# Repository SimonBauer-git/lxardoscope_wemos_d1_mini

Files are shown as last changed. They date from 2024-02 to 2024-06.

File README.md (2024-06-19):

# lxardoscope_wemos_d1_mini
this is a single channel low frequency oscilloscope using a wemos d1 minis internal adc. you can use it just with the board itself but i have made a little daughterboard which that makes it more like a real oscilloscope.
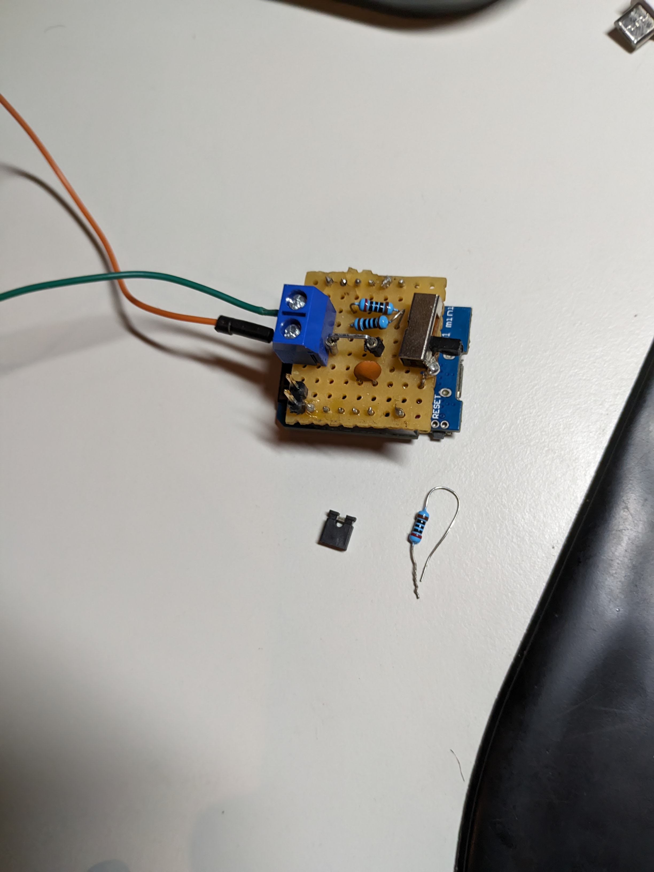
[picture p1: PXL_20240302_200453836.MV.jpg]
Alt the little daughterboard on the wemos board (able to meassure ac)

this is version 2 of the daughterboard, it can meassure ac voltages with the use of a voltage devider. you need a 200k resistor depending on the voltage meassured.
## continous aquisition
with continous aquisition (i.e. reading one sample, then transmitting that), 45ksps is possible or 22.5khz (so anything in the audio frequency range). 62ksps is possible or 31khz if you change the cpu frequency to 160mhz (can be done in arduino IDE). this methode is particularly suited for low frequency stuff.
## buffered aquisition 
by reading a lot of samples (in this case 24k) and then transmitting them in bulk much greater sampling rates are achivable, how much I am not sure of myself as due to the pulsed nature of the datastream the lxardoscope application doesnt show it correctly, I tested it with a 1 microsecond pulse though and it showed up as a squarewave, that was ok in terms of stability, so atleast 500khz. I have done some tweaks to make the trace more stable, particularly at frequencies below 1khz, i have asigned fixed values to tspan and nbchar in lxa_ard.c, to match the hardware.
# using it on x86 linux
just download the lxardoscope code for linux, specify 2000000 BAUD in the code and use it, no extra steps required if you use the continous sampling methode, if not use my code.
## using it on windows
either use a linux vm and then do the same as on x86 linux or use wsl. you need wsl-usb to be able to use the usb from the computer on wsl.
## using it on android (no longer in active developement)
this is no longer in active developement due to application stability issues, you can however mod the code like described above and below.
Alt my scope running on an android tablet
### with proot-distro already setup with a desktop enviroment
just download the folder android from here. you need to install libforms-dev and ibforms-bin to use it and to compile it. you need the app tcp uart transparent bridge, specify it to be server in the app.
https://play.google.com/store/apps/details?id=com.hardcodedjoy.tcpuart
to use it open a terminal in the folder, type ./scopeconnect.sh (assuming you made it executable with chmod +x or in the gui at first) then type ./lxardoscope (if the programm crashes the first time, then repeat this step). and afterwards you can use it.
### simple setup, just the scope
if you only want the scope and nothing more, just install termux, termux x11 and tcp uart bridge. open termux, then do these steps

1. pkg update
2. pkg upgrade
3. pkg install x11-repo termux-x11-nightly
4. pkg install proot-distro
5. proot-distro install debian
6. wget https://raw.githubusercontent.com/SimonBauer-git/lxardoscope_wemos_d1_mini/main/android/simple-setup/scope.sh
7. proot-distro login debian
8. apt update
9. apt upgrade
10. apt install libforms-dev libforms-bin libx11-bin libx11-dev
11. wget https://raw.githubusercontent.com/SimonBauer-git/lxardoscope_wemos_d1_mini/main/android/lxardoscope
11.1 wget https://raw.githubusercontent.com/SimonBauer-git/lxardoscope_wemos_d1_mini/main/android/lxardoscope_0.95_android_sampling.vfast/lxardoscope
12. chmod +x lxardoscope
13. wget https://raw.githubusercontent.com/SimonBauer-git/lxardoscope_wemos_d1_mini/main/android/simple-setup/proot-distro/scope.sh
14. chmod +x scope.sh
# Function Generator:
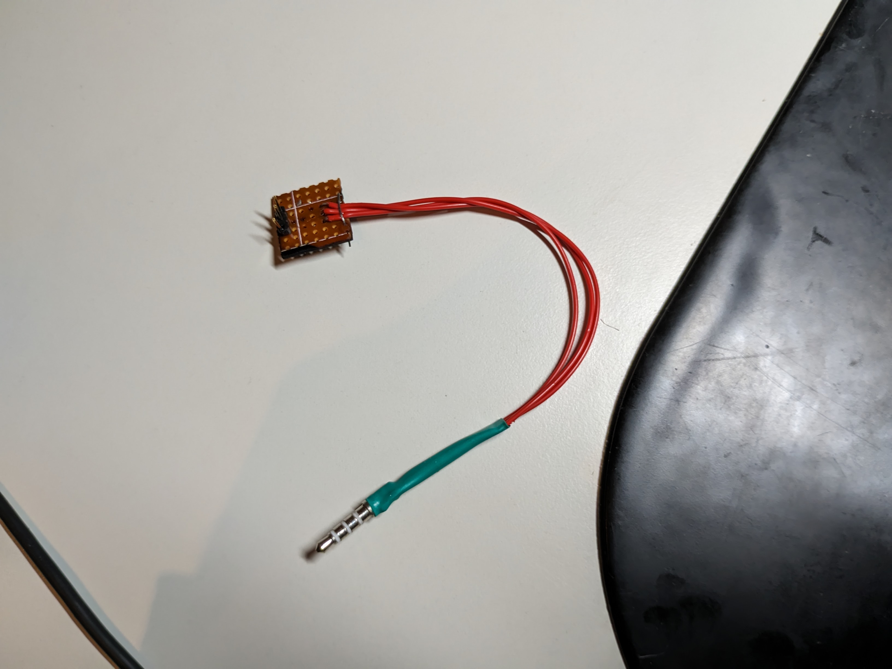
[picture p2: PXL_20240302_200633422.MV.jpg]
function generator

A very simple function generator, using an audio jack output (Frequency limited to whatever the device can provide). daughterboard breaks out left and right channel along with ground to pins, no electronics involved, just a direct connection. you can use something like this to create the waveforms, no install required, just use it: https://cse.unl.edu/~jfalkinburg/husker-scope/app/page/FunctionGenerator
or if you want an android app that has a different interface and a bit more functions look here: https://play.google.com/store/apps/details?id=com.keuwl.functiongenerator

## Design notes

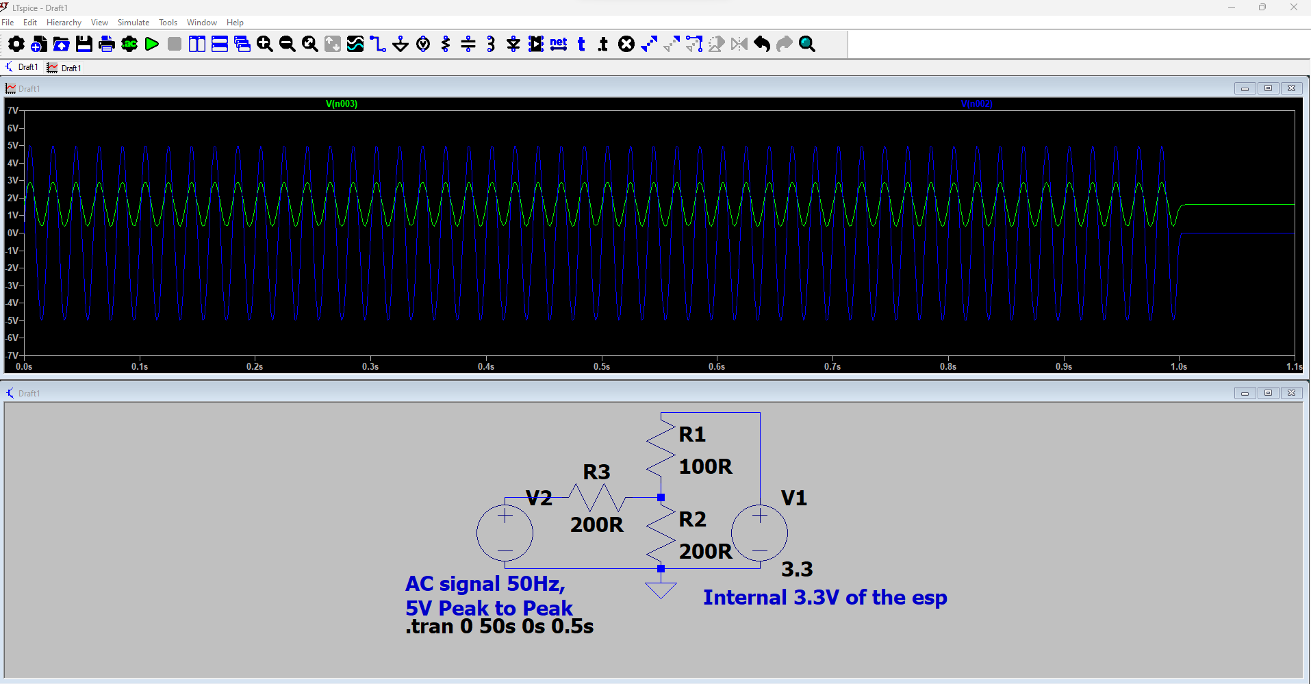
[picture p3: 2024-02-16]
schematic/wemos shield v2/Screenshot 2024-02-16 115349.png

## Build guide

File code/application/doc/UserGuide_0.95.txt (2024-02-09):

/*
 *
 * This file is part of the LXARDOSCOPE package.
 *
 * LXARDOSCOPE is an Arduino based oscilloscope for Linux, using the Xforms library.
 *
 * Copyright (C) 2013 Oskar Leuthold
 * 
 * LXARDOSCOPE is free software: you can redistribute it and/or modify
 * it under the terms of the GNU General Public License as published by
 * the Free Software Foundation, either version 3 of the License, or
 * (at your option) any later version.
 *
 * LXARDOSCOPE is distributed in the hope that it will be useful, but
 * WITHOUT ANY WARRANTY; without even the implied warranty of
 * MERCHANTABILITY or FITNESS FOR A PARTICULAR PURPOSE.  See the GNU
 * Lesser General Public License for more details.
 *
 * You should have received a copy of the GNU Lesser General Public
 * License along with LXARDOSCOPE; see the file COPYING.  If not, write to
 * the Free Software Foundation, 59 Temple Place - Suite 330, Boston,
 * MA 02111-1307, USA.
 *
 */

Introduction
************
LXARDOSCOPE (LinuX-ARDunio-oscillOSCOPE) is a software implementation of an 
oscilloscope in LINUX, using the Analog-Digial converter of an ATmega328 device
or an ArduinoUNO board for data acquisition. 
My goal was to keep the LXARDOSCOPE GUI as intuitive as possible for users who are
familiar with hardware oscilloscopes. I am assuming that the vast majority of 
users fall into this category, since this is a measuring instrument for use with
electric circuits. Therefore this user guide does not cover how to use an 
oscilloscope; tutorials for oscilloscopes are available on the internet. Extra
functions provided here should be self explanatory - otherwise submit a request
for clarification through the Sourceforge support page.
When LXARDOSCOPE is running on my laptop, with CPU clock at 1.8GHz, under
Mint 13, LXARDOSCOPE needs about 2% CPU time with 5 seconds of data displayed.
Xorg's graphics engine needs more, depending on the amount and extent, basically
how many pixels must be processed.  
Lxardoscope_0.95 is designed to work with a preamplifier, which is described
in a separate document, LxaPreamp.txt. This program allows for controlling the 
GND/AC/DC configurations of the preamplifier from the GUI.

Features
********* 
	- display modes: two channels, time/add/xy
	- vertical: 2mV to 10V per division
	- overall gain control for calibration
	- horizontal: 2ms to 5 sec (full sweep)
	- trace position adjustments: vertical and horizontal
	- trigger: on/off, channel and edge selection
	- trigger level: -10 to +10V
	- hysteresis up to 5V
	- signal measurements: max, min, pp, avg, rms
	- display signal levels and timing at cursor position
	- close to 2500 samples per second, per channel
	- option for reviewing snapshot of data
	- option for recording input data stream to file
	- option to display recorded data from file
	- timebase calibration adapting to ADC's conversion speed
	- remote control of GND/AC/DC circuit configurations of the preamplifier.
	- highpass with corner frequency of 2.5Hz in AC mode

Arduino vs ATmega328
*********************
The Arduino UNO board contains the ATmega328 circuit and a chip to communicate
with the USB port of a host computer. Most of the time I use the ATmega328 DIL
circuits on breadboards, with a CP2102 based TTL/USB module for communicating
with the computer's USB port. I prefer the modules from BAITE (available on 
Ebay), which allow for easy replacing the RESET signal with DTR. 
All the detailed testing was done with the ATmega32 on breadboard with the 
BAITE module. The ArduinoUno works fine with this program on Mint9, but not re-
liably on Mint13, for unknown reasons. When connecting a BAITE device to the TX
pin of the Arduino board, I got the expected behavior. So the wiring was correct;
it seems like Mint13 and the TTL/USB converter implemented on the ArduinoUno do
not get along with each other. If you have an idea what is going on, then please
let me know through Sourceforge.

LXARDOSCOPE differences with respect to a conventional oscilloscope:
********************************************************************
The display is not updated continuously, but rather shows a snapshot of the data 
approximately every 300ms. Thus with long time scales, the waveform seems to
move from right to left; therefore a particular event can show up several times.
As opposed to an analog oscilloscope, which operates with signals continuous in
time and levels, LXARDOSCOPE works on the data points from the ATmega, which 
converts the real signal to discrete samples in time and levels. The display
shows simple linear interpolation between these data points, which is admittedly
in general a poor approximation of the true signal. Another source of discrepancy
are signal components input to the ATmega above 1.2kHz (half the sampling rate);
they appear folded into components below 1.2kHz. This folding process is not 
specific to this application, but rather a general property of any sampling
process. And finally the fact that the ATmega samples the two channels in an
alternating fashion creates additional artifacts (see below).     
In LXARDOSCOPE the time base setting is in terms of full scale, not graticule
division. This is based on considerations of the scaling process. For example,
if full scale is set to 12ms, the LXARDOSCOPE graticule shows 13 vertical
lines at 0, 1, 2 ...  10, 11, 12 ms, which is easy to read. On a division based
approach, always 10 divisions are used. For 12ms full scale, the increments are
1.2, thus producing grid lines at 0, 1.2, 2.4 .....10.8, 12, which are much less
convenient to read. 

Development
***********
LXARDOSCOPE version 0.95 has been developed and tested on Linux Mint13 (32bit)
with ATmega328 devices, using the included lxardoscope95.ino (in the ATmega 
directory). 

Installation
************
The downloaded file contains an executable, which hopefully works on your computer.
The appropriate XFORMS executable is linked statically, to simplify installation
and to eliminate problems with incompatible versions of the library, which might
exist on the host computer.
After unpacking the downloaded file, cd to the lxardoscope directory and type
" ./lxardoscope " (without quotes).
For a general installation, type
either " sudo make install "
or " sudo cp lxardoscope /usr/local/sbin "
After installation, the system wide start command is " lxardoscope ".

If the supplied executable does not run on your system, you can re-compile:
1. install libx11-dev (using apt, Synaptic)
2. build:   " make "
4. install and run as above

If these steps do not work, you have to rebuild the Xforms library, which will
produce a new libforms.a. LXARDOSCOPE requires XForms Version 1.0.93sp1. The
directory xforms-1.0.93sp1_ext contains the files which might have to be updated.
The XForms source package is available at 
	http://savannah.nongnu.org/projects/xforms .

Port issues
***********
On Ubuntu style LINUX distros, when connecting the Arduino UNO to the USB port, a
device with a name starting as ttyACM is created in the /dev directory, which can
be accessed like a regular serial port. If you remove the Arduino and reconnect
again, the port number might change, for example from ttyACM0 to ttyACM1.
With the CP2102 based Serial-to-USB converter circuits mentioned above, a device
with a name starting as ttyUSB is created.
If you have a computer with a serial port, then you can connect to an ATmega328
using a simple inverter, as shown in ATmega328simple.png. The schematic 
Interface.png shows a solution with a MAX232, and how optocouplers can be
used to insulate the supplies of the ATmega (and with it the analog signal
processing circuitry) from the PC. When working with the regular serial ports,
keep in mind that the signal levels can be up to 15V. Some integrated circuits
are destroyed if such a high voltage is applied to a pin.

How to get started
******************
First you need to program the ATmega with the supplied sketch lxardoscope95.ino 
from the ATmega/lxardoscope95 directory, using the Arduino IDE or Gnoduino
(used on Mint9, but not on Mint13).
Connect your analog signals to the preamplifier inputs.
Two startup modes are available:
1. choose serial port at startup:
   type " lxardoskope /dev/ttyXXXX " with XXXX being the device name/number. The
   program tries to initialize this port, but others can be selected later.
2. choose serial port on GUI:
   type " lxardoskope " . After starting up, the "Port" pulldown of the GUI is
   populated with the port choices available from the /dev directory. The list
   includes device names which start with "ttyS", "ttyACM" or "ttyUSB".
If the selected port is busy due to some other process, then the initialization
fails. A message is displayed in the terminal where LXARDOSCOPE was started,
if the selected device is not available. 
On success, the START button under the waveform area is enabled. Clicking the
button starts the GND calibration routine. The scope display shows the calibration
results (in units of LSB [least significant bits of the ADC]) for both channels.
The numbers are close to 400 for the preamplifier described in LxaPreamp.txt, 
because the ATMEGA reference voltage is 3V and the actual voltage coming into
the ADC is 1.2V, when the preamplifier input is connected to GND.
After calibration, the ATMEGA device starts acquiring the input signal and 
LXARDOSCOPE displays the data. The pulse indicator changes color from grey, 
and then blinks in response to the serial data stream from the ATMEGA. 
At least some horizontal lines should be displayed, maybe already some waveforms.
Then make the necessary adjustments to the timebase and vertical scale and
position, as on a conventional oscilloscope.
In display mode ADD, position and scale are taken from channel 1; entries for 
channel 2 are disabled. In display mode X-Y, the selected trigger channel is 
displayed in horizontal direction (independent whether triggering is enabled or
not). 
When triggering is enabled, source channel, edge, trigger level and hysteresis
can be selected. The displayed waveform can be shifted to the left or to the 
right, up to 500ms. This is useful for inspecting what happens immediately before
the trigger time point. 
The displayed signals can be measured by placing the cursor with the mouse and
clicking at the time slice of interest. Time and levels are reported in the
" Signal Values " box. The measurement applies to the data displayed at the
moment the selection is made; the value is not continuously updated sub-
sequently.
After clicking the START/STOP button again, acquisition of new data stops and
the internally stored waveforms can be inspected. Vertical Position and Scale,
horizontal Full Scale and (with trigger) DisplayShift functions allow for zooming
into the waveform. With DisplayShift, about half a second of data can be reviewed
and measured using the cursor. 
  
Storing and reviewing data stream
*********************************
The data stream coming from the ATmega can be recorded to a file by clicking the 
"Record" button before the "START" button. A new window pops up for entering
the name of the new file (suggested extension is "raw"). When finished recor-
ding, click the "STOP" button, and toggle the " Record " button to stop recor-
ding and to save the file. The "Record" button is disabled when LXARDOSKOPE is
running. The raw file contains 16-bit (2-byte) sample values, for both channels,
no information on data rate. Of the 16 bits, only 10 are used, because that's 
what the ATmega analog-digital converter delivers. 
To inspect a raw file, select "file" on the "Device" pulldown (last entry). 
A new window pops up for selecting the raw file. The file is loaded, and
the beginning is displayed. The GUI changes in the Timebase area. A counter is
added for navigating in the file under the Full Scale counter, with the following
functionality:
	- single right arrow: shift display to later data, by 20% of full scale.
	- double right arrow: shift display to later data, by 80% of full scale.
	- singe left arrow: shift display to earlier data, by 20% of full scale.
	- double left arrow: shift display to earlier data, by 80% of full scale.
The amount of shift is close to the values indicated; differences are due to
rounding.
Between the navigation buttons, the position of the first sample, shown on the
left side of the waveform display, is indicated, in units of milliseconds.
Commas are used to separate the seconds from the milliseconds, and the seconds
from the thousand seconds. This area is actually an input field, accepting a 
floating point number; the blue vertical line shows the position of the cursor.
In the waveform display area, a yellow line is shown at the end of data, to
distinguish from the case when the data itself is zero.
A 4-digit pushwheel widget allows for setting the Sampling Rate, between 1000
and 5000 samples per second. For accurate time measurements, the value must be
set to the one reported when recording the file (using the Verbose button). 

Communication with the ATmega and Preamplifier
**********************************************
Each channel has 4 separate modes of operation. A corresponding code is sent
to the ATmega device upon selecting a new entry. With the preamplifier described
in the document LxaPreamp.txt, the codes and associated features are shown in the
following table:

		channel1	channel2
mode	code		code
GND		1			4			GND calibration: preamp input connected to GND
DC		2			5			DC: input range is -4V to +6V
AC		2			5			AC: input range is -4V to +6V
AC 10X	3			6			AC with gain: input range is +/-0.5V

When the START button is pressed, a GND calibration is executed for both channels.
In the two AC modes, a highpass filter is implemented in this LXARDOSCOPE program
with a corner frequency of 2.5Hz. 
LXARDOSCOPE adjusts the scaling factor automatically when selecting the AC 10X
mode. If the gain of the preamplifier is different, then you can click the 
"Options" button in the ATmega field and change the gain value in the popup
window. Acceptable values are integers between 1 and 10 (inclusive), with default
at 10.

Sampling rate
*************
When using the supplied lxardoscope95.ino for the ATmeg328, with the transfer
rate of 115200 baud, LXARDOSCOPE starts up assuming 2500 samples per second. The 
actual rate at which data is delivered is continuously measured and the display
settings updated in regular intervals.  
After pressing the push button "Verbose", the actual sampling rate is reported in
the terminal.  
Preliminary tests indicate that the time required for analog-digital conversion
is about the same as the data transfer time; thus by speeding up the data
transfer, the converter becomes the bottleneck (unless accuracy is sacrificed
for speed). Therefore LXARDOSCOPE version 0.95 supports only a fixed transfer
rate of 115200 Baud. 

Alternate Sampling
******************
The ATmeg328 samples channel 1 and channel 2 in an alternating fashion; this means
not at the same time. In "Time" mode, LXARDOSCOPE displays channel 2 delayed
by half a sample with respect to channel 1. Thus when feeding the same signal
into both channels, they line up correctly; although for higher frequency signals
the data points can clearly be seen as alternating.
In "ADD" mode, the signals are interpolated and shifted, such that when feeding
the same signal into both channels, and inverting one of them, the resulting
signal is very small.
In "XY" mode, the signals are not adjusted; therefore when feeding the same
signal into both channels, the delay can clearly be seen: for a sine wave, an
oval shape is shown. 
When feeding identical square waves into both channels, things get really ugly...

ATmega code
***********
The .pde file from previous versions had to be updated to work with Arduino1.0;
lxardoscope95.ino is the new version. The upgrade of the Arduino software required
changes in the communication part: 
	Serial.print(lb|96,BYTE);
replaced by 
	Serial.write(lb|96);
Due to some clever un-optimization from the Arduino folks, this simple change
causes the program to produce a sample rate of 2441 instead of 2940. The addi-
tional code required for programming the relays of the preamplifier and port
switching cause another reduction in sampling rate to 2349. Optimizing this code
by using direct addressing of the peripherals should be a fun and rewarding
exercise. However at that point one might just go for overall higher speed,
including higher transfer rate on the port (subject of the next LXARDOSCOPE 
version?).
In the sketch lxardoscope95.ino, the loop section is digitizing the signals on
ports A0 and A1 in DC mode, and on ports A2 and A3 in AC mode, and sending the
result after some formatting through the serial port to the USB link. In the
middle and at the end of the loop, port 8 is switched to produce a square wave,
which is used to drive the auxiliary power supply of the preamplifier. 
Finally the serial port is checked for input, and the digital outputs set to
high or low, according to the incoming number. See also the previous section 
"Communication with the ATmega and Preamplifier" on the definitions of the codes.
The characters * and # can be used to toggle the state of digital output 13, 
where an LED is connected on the ArduinoUno. 
Note that these numbers and characters can be communicated to the ATmega chip
through other programs, for example the Serial Monitor of the Arduino software
or Cutecom.  

Screen Capture
**************
The file lxardoscope_T.png contains a screen capture of the LXARDOSCOPE board and
the software in action. A 293.6 Hz sine wave and a 1174.5Hz sine wave from a 
sound card based generator (LXIGGEN) are displayed. The sampling rate is 2349
samples per second. So the higher frequency signal is sampled twice per period,
at the top and at the bottom (need to wait for this condition; trigger helps).
The low frequency sine wave is sampled 8 times per period; that's why it looks
ugly (LXARDOSCOPE offers only straight line interpolation between data points).
The screen shot lxardoscope_XY.png shows an XY plot of a 50Hz sine wave on
channel 1 and a 250Hz sine wave on channel 2, produced with LXIGGEN. The Lissajous
figure displays nicely the frequency ratio of 5. 

Measurement results
*******************
See the file LxaPreampMeasurements.pdf in the doc directory for characterization
results of the preamplifier in conjunction with the ATmega ADC, using a soundcard
based measurement system.

History
*******
LXARDOSCOPE is based on an XOSKOPE-0.5 (eXtended oscillOSKOPE), released in 2001,
created by J.Fernando Moyano (http://xoskope.sourceforge.net), and LXOSKOPE, 
released in 2011 (available from http://lxoskope.sourceforge.net). These pre-
decessors use the sound card for data acquisition instead of an ATmega device.

Acknowledgement
***************
Thanks to J. Fernando Moyano for XOSKOPE for creating the first version. 
Thanks to Dr. Zhao for creating the XFORMS library, which is used for the GUI.
Thanks to Tim Witham for XOSCOPE, an early oscilloscope program which is still
widely distributed.
 
I hope you find LXARDOSCOPE useful. 
Please submit comments to the support page of LXARDOSCOPE on Sourceforge.

August 8, 2013 Oskar Leuthold

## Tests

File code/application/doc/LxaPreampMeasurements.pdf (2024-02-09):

Measurements on Preamplifier for LXARDOSCOPE
The measurement results presented here were generated using the LXSNDTEST utility, available from Sourceforge. The program works with a sound card in duplex mode, driving the device under test (DUT) with accurately defined waveforms, and receiving the signal from the DUT. The data from the sound card is processed using FFT to determine the characteristics of the DUT.
High quality sound cards are well suited for these kind of measurements, because they work with signals in a similar range as the preamplifier. A parameter which summarizes the quality of a signal path is the number of bits (ENOB). High quality sound cards show values in excess of 13 bits for the path digital input → analog out →analog in → digital out.

### 1 Phase/Frequency response of DC path

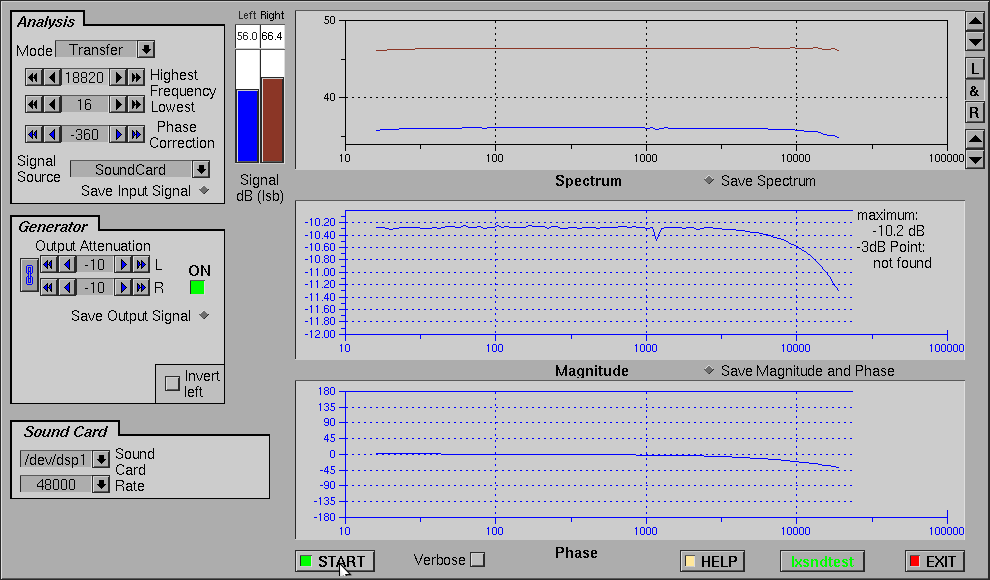
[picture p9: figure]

This response was measured from the preamplifier input to the amplifier output of the DC path, before the lowpass filter. The response drops by about 1dB at 18kHz, which is way above what the ATmega ADC can handle (theoretically half of 2350Hz, which is 1175Hz).
The top graph shows the input and output signal on the same scale. The middle graph shows the difference in frequency response from input to output. This is effectively the amplitude response of the preamplifier. The bottom graph shows the phase response of the preamplifier. The spike around 1200Hz is probably due to the switching noise of the ATmega device, which needs to be running in order for the reference voltage generator to work.

### 2 Phase/Frequency response for AC path with gain

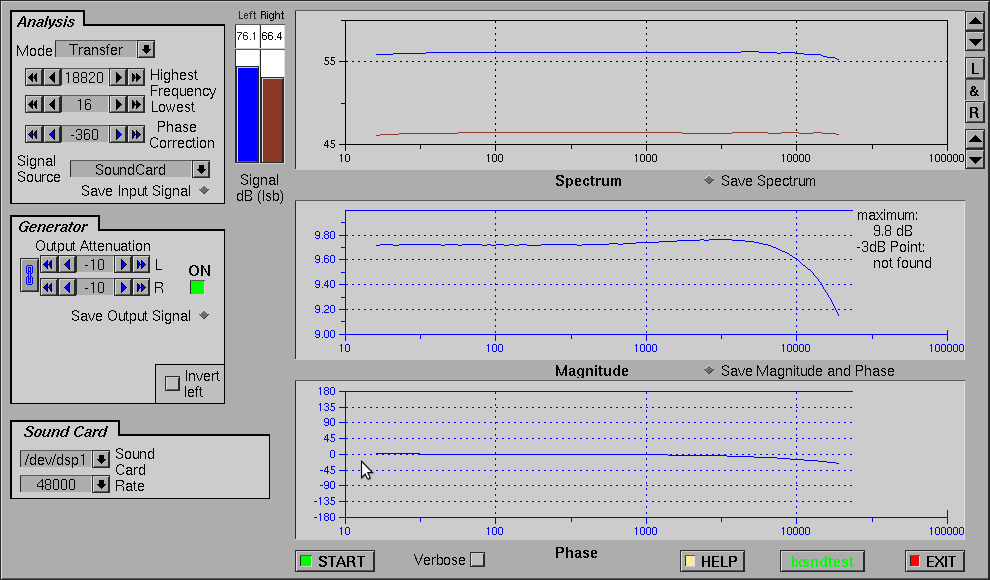
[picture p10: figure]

This response was measured with a sound card from input to the amplifier output of the AC path. The frequency response drops by less than 1dB at high frequency, which is way beyond the frequency which the ATmega device can handle. The low frequency gain is 9.8dB.

### 3 Distortion measurements

In the next two chapters, the results are presented from distortion measurements using a sound card as generator and input device.
In the subsequent chapters the results are presented where a sound card is used as sine wave generator and the preamplifier is actually driving the ATmega ADC. The LXSNDTEST picks up the ADC output through the USB port.

### 4 Distortion of DC path

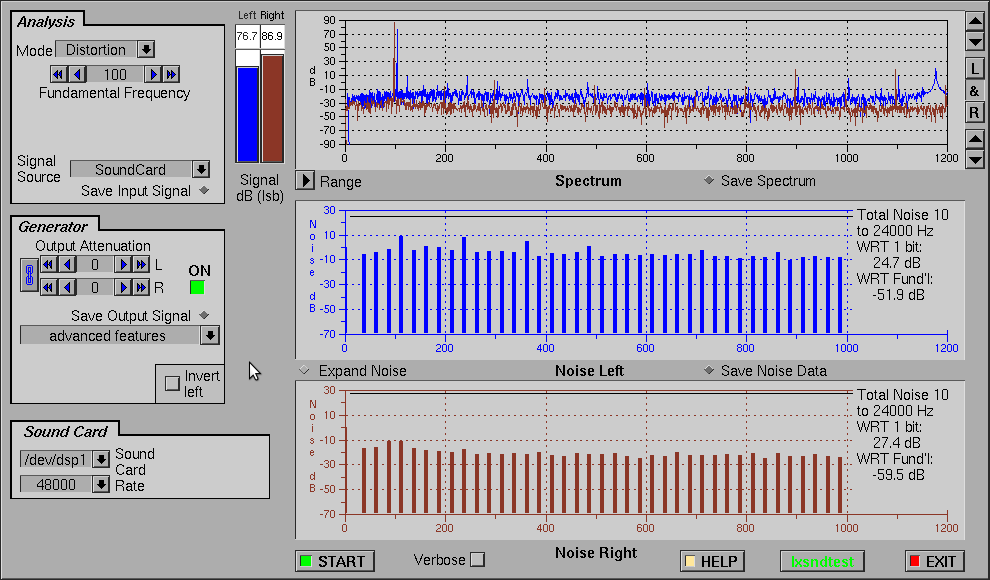
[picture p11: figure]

The top graph shows in the right channel the spectrum at the input of the preamplifier, with an input signal of 100Hz, and in the left channel the spectrum of the signal at the output of the amplifier of the DC path (before the lowpass filter). The attenuation is 86.9-76.7dB=10.2dB.
The table below shows the parametric results for the preamplifier, with numbers for the right channel representing the input, and the numbers for the left channel representing the DC path:
– signal swings,
– the level of the fundamental with respect to 1-bit of the sound card, – the distortion,
– effective number of bits,
– signal-to-noise ratio
– signal-to-noise-and-distortion ratio

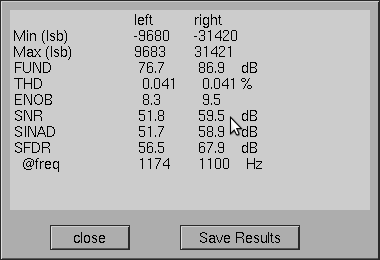
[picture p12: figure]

– spurious free dynamic range, and the frequency at which the highest spur occurs.
The results are pretty good. For further investigations, a generator with lower noise would be required.

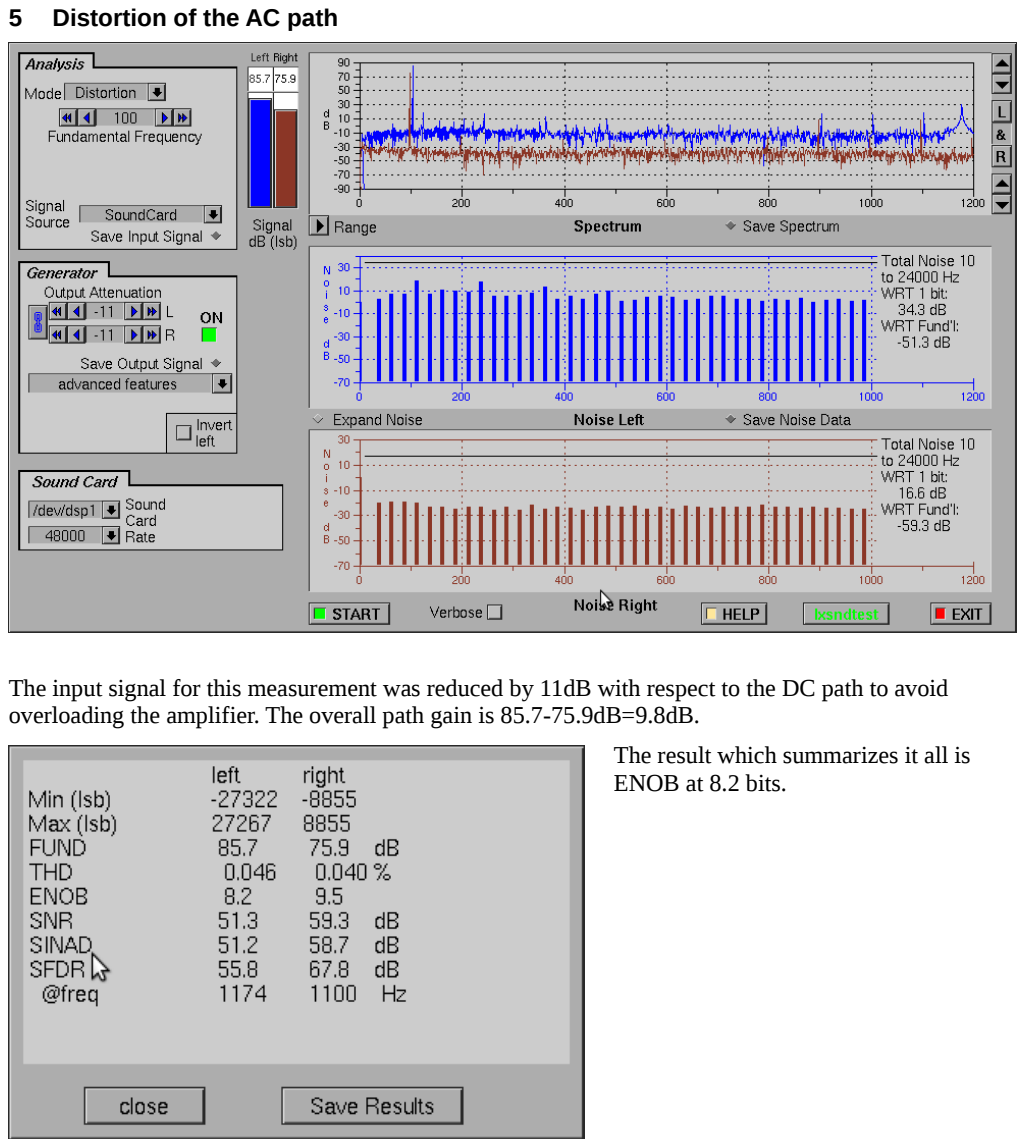
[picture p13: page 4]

### 5 Distortion of the AC path

The input signal for this measurement was reduced by 11dB with respect to the DC path to avoid overloading the amplifier. The overall path gain is 85.7-75.9dB=9.8dB.
The result which summarizes it all is ENOB at 8.2 bits.

### 6 Distortion of DC path with ATmega ADC

The signal swing is 366 bits from the ATmega ADC, which represents 36% of full scale. Considering that distortion is low with respect to the overall noise (from quantization etc), the result for ENOB with a full swing signal should approach 8 bits.

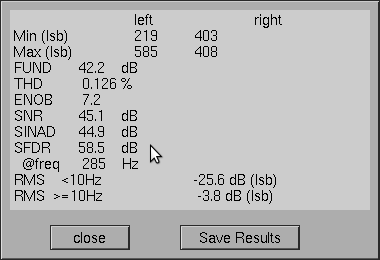
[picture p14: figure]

### 7 Distortion of AC path with ATmega ADC

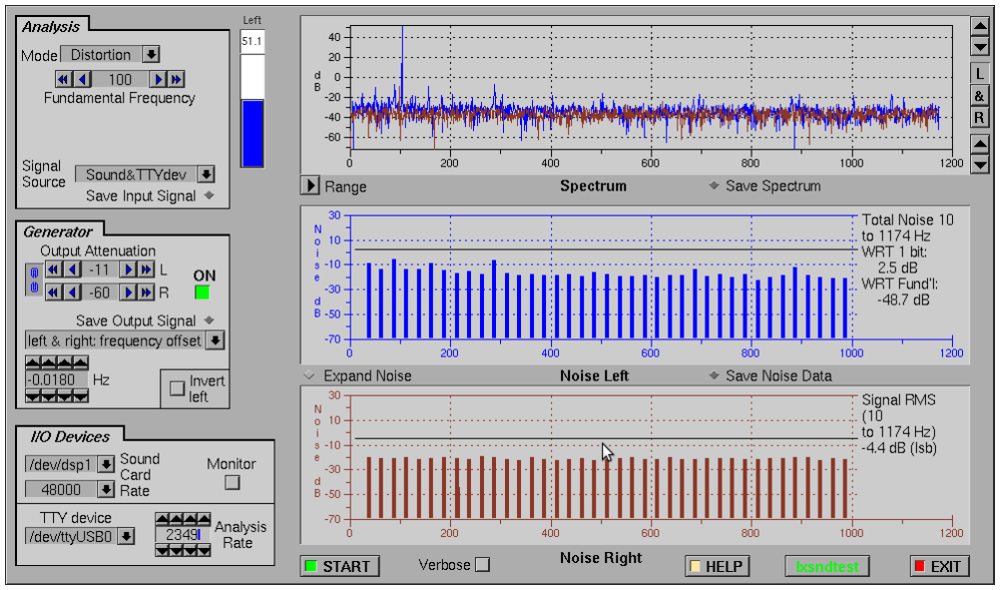
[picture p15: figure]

The screenshot from the LXSNDTEST GUI shows on the left side the setup required to measure distortion from an ATmega device. The generator is (empirically) set to -11dB, to get the maximum output signal without distortion. The frequency of the sine wave is 100Hz with an offset of -0.018Hz, to achieve an exact integer number of periods in the interval where the ATmega is producing 2349 samples per second for each channel.

The input signal is driving the ADC exactly full scale in this case. The
ENOB result is slightly higher than for the DC path (was 7.2 bits), probably due to the difference in input signal.

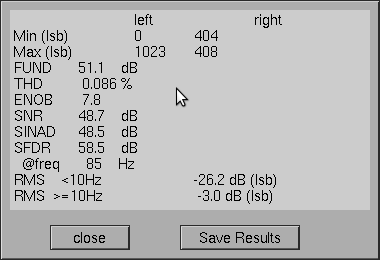
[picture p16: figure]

### 8 Conclusion

Considering that the prototype was built on a plugin breadboard, the results look good. The frequency response extends about 10 times as much as required. The effective number of bits is close to 8, which is good enough for an oscilloscope application. Many low cost oscilloscopes digitize only to 8 bits, thus certainly producing an ENOB result below 8 bits.

August 6, 2013 Oskar Leuthold

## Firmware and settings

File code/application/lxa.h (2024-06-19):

/*
 *
 * This file is part of the LXARDOSCOPE package.
 *
 * LXARDOSCOPE is an Arduino based oscilloscope for Linux, using the Xforms library.
 *
 * Copyright (C) 2013 Oskar Leuthold
 * 
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
 */
# define DEFAULT_REFRESH_TIME 0.3
// update rate for the display (seconds)
#define DEFAULT_SAMPLING_RATE 2500
// baud rate of 115200 programmed as B115200
#define DEFAULT_BAUD_RATE 6000000
// DEFAULT_SAMPLING_RATE and DEFAULT_BAUD_RATE and DEFAULT_REFRESH_RATE
// determine the following interrelated buffer sizes. Do not change!
#define TBUF_CHUNK_SIZE 256 * 8
#define TBUF_NB_CHUNKS 128
#define TBUF_SIZE (TBUF_NB_CHUNKS * TBUF_CHUNK_SIZE)
#define RBUF_CHUNK_SIZE (2 * TBUF_CHUNK_SIZE)
#define RBUF_NB_CHUNKS 8
#define RBUF_SIZE (RBUF_CHUNK_SIZE * RBUF_NB_CHUNKS)
#define DATXY_SIZE 32768
#define VBUF_SIZE 65536
//
#define DEFAULT_REFERENCE  5.0
#define DEFAULT_TIME_OFFSET 0.0
#define DEFAULT_TIME_SCALE 10.0
#define DEFAULT_TRIG_LEVEL 0
#define DEFAULT_HYST 0.01
#define DEFAULT_TRIG_CHANNEL 0
#define DEFAULT_V_SCALE 2.0
#define DEFAULT_ADD_MODE 1			// use interpolation between channels
#define DEFAULT_COEFF 0.01			// highpass coefficient
									// -6dB @ 3Hz with 3000 samples/second

enum OPERATION_MODE {
			    OPERATION_MODE_NORMAL=0,
			    OPERATION_MODE_ADD=1,
			    OPERATION_MODE_XY=2
			   };
typedef enum{ ASC_TRIG=0, DESC_TRIG=1 } TRIG_TYPE;
typedef enum{ TRIG_OFF=0, TRIG_ON=1 } TRIG_ENB;

typedef struct {
 float reference;
 float sampling_rate;
 int baud_rate;
 int op_mode;
 int nbsamples; 		// number of samples per chunk 
 int disp_size;			// this is the full number of data points to be plotted,
						// as a function of Full Scale and effective sampling rate. 
						// Typically is some round value 
						// plus one, due to the data point at zero.
 int disp_mode;			// 0: normal  1: review, if stopped
 int disp_start;		// index of first sample to be displayed in normal mode
 int disp_actual;		// this is the actual number of data points to be plotted.  
 int disp_max;			// this is the maximum number of data points
 char devices[12][20]; 	// for serial port names: /dev/ttySX
 int verbose;
 char device_name[20];
 int dev_h;				// soundcard device handle
 int rchunk;     		// number of chunks read in
 int cchunk;     		// number of chunks copied
 int tchunk;			// number of chunks in tbuf (from 0 to 63)
 int datend;			// index of last valid data point in tbuf
 int trig;				// trigger index
 float delta;			// display shift due to trigger (less than one sample)
 int threadenb;			// enable flag for reading thread
 int record;			// flag for writing data to raw file 
 const char *rfname;	// name of output raw file
 int rhandle;			// handle of output raw file
 int ifile;				// flag for reading data from raw file instead of Arduino
						// 0: Arduino  1: file open, reading  2: finished, file closed 
 const char *ifname;	// input file name
 int ifsize;			// input file size (samples for each channel)
 FILE *ihandle;			// input file handle
 long int ifdatapos;  	// input data position
 long int ifvb_last;		// input file sample copied into last place of vbuf
 long int ifvb_first;	// input file sample copied into first place of vbuf
 float input_pos;			// user input value for file position
 int run;				// flag for processing and displaying data
						// 0 stopped (initially waiting for user input
						// 1 processing and displaying running
						// 2 review mode (must have run before)
 int vcount;			// number of samples in vbuf (used with file input)
 int vstart;			// first sample to be displayed (with file input)
 float charspersec;		// characters per second (as calculated in lx_run)
 float wx;				// pointer x value
 int pulse;
 int orchunk;
 char *texts[10];		// text pointers for annotating display
 int nbtexts;			// number of texts
 char tdisp[30];		// stores string for time legend
 char msgdisp[100];		// screen message
 float coeff;
} base_info;

typedef struct {
 int trig_chan; 
 float T_pos;         	// time offset
 float T_scale;       	// this is value from GUI counter, full display time
                      	// due to scaling issues, the notion of time per div
						// is much less convenient.
 float trig_level;
 float hyst;
 TRIG_TYPE trig_mode;
 TRIG_ENB trig_enb;
} horizontal_info;

typedef struct {
 int on[2];
 FL_COLOR color[2];
 float V_pos[2];
 float V_scale[2];
 int inv[2];
 float min[2],max[2],pp[2],rms[2],avg[2];
 int minvalue[2],maxvalue[2];
 int gndcalseq;			// sequencer for gnd cal; mostly advanced by display timer
 int gndcal1,gndcal2;	// flag for GND calibration ( 0 cal not performed
						// 1 when cal performed, 
						// 2 in progress etc)
 int acdc1,acdc2;		// flag for AC/DC (0 @ DC, 1 @ AC with gain=1, 2 @ AC with gain)
 float calvaldc1,calvaldc2;
 int acgain1,acgain2;
} channel_info;

extern FD_lxa *lxa;
extern base_info LX;
extern channel_info CHAN;
extern horizontal_info HOR;
extern float datx[2][DATXY_SIZE];
extern float daty[2][DATXY_SIZE];
extern float tbuf[2][TBUF_SIZE];   	//temp buffer for channel 0
extern signed short rbuf[];	//read-in buffer
extern 	char uparrow[];
extern 	char dnarrow[];
extern 	char *CH[2];
extern	char tdisp[];
extern char msg[100];

int timeval_subtract(struct timeval *tresult, struct timeval *tx, struct timeval *ty);
int pro_display(FL_OBJECT *xyplot, int mode);
int plot_file(FL_OBJECT *xyplot, int button);
int open_dev();
void close_dev();
void *lx_run(void *arg);
double rmsq(int r, double c, double d, double e);
void set_counter_Tscale(FL_OBJECT *ob);
void set_f_counter_Pos(float val);
void dispmsg(char *);

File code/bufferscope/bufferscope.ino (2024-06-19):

#include <ESP8266WiFi.h>

uint16_t adc_addr[24832];
uint16_t i=0;
void setup() {
  WiFi.mode(WIFI_OFF);
  Serial.begin(2000000);
  ets_intr_lock();  // close interrupt
  noInterrupts();
  scope();
}
void loop() {
}

void scope()  //have an extra function that does the looping as this is faster than void loop
{
  while (true) {

    system_adc_read_fast(adc_addr, 24832, 1);
    i =0;
    while (i<24832){ 
    Serial.write(0x80 | adc_addr[i] >> 4);
    Serial.write((adc_addr[i] << 3) & 0x70);
    i++;
  }}
}

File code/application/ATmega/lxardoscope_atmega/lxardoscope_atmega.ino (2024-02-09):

#define BUFSIZE 256
uint8_t cbuf[3] = {0x80, 0x00, 0x00};
#define CH1 0x1
#define CH2 0x2
#define BOTH 0x3
uint8_t channels = BOTH;

#define ADMUX_INIT B00000000 /* 00 ext reference, 0 right adj, 0filler, 0000 source */

void setup()
{
  Serial.begin(1000000);
  ADCSRA = 0;
  ADCSRB = 0;
  ADMUX = ADMUX_INIT; 
  //ADCSRA = B11101100; /* 1enable, 1start, 1trig, 0int, 1intenable, 100 prescaler 16 */
  //ADCSRA = B11101111;
  ADCSRA = B11001100; /* 1enable, 1start, 0trig, 0int, 1intenable, 101 prescaler 32 */
}

uint16_t val[2];

ISR(ADC_vect)
{
  uint8_t chan = ADMUX & 1;
  val[chan] = ADCL;
  val[chan] |= ADCH << 8;
  switch (channels) {
    case 0:
      ADMUX = ADMUX_INIT;
      ADCSRA |= B01000000;
      Serial.write(cbuf, 2);
      break;
    case CH1:
      ADMUX = ADMUX_INIT;
      ADCSRA |= B01000000;
      cbuf[0] = 0x80 | val[0] >> 3;
      cbuf[1] = (val[0] << 4) & 0x70; 
      Serial.write(cbuf, 2);
      break;
    case CH2:
      ADMUX = ADMUX_INIT | 1;
      ADCSRA |= B01000000;      
      cbuf[0] = 0x80;
      cbuf[1] = val[1] >> 6;
      cbuf[2] = val[1] & 0x7F;
      Serial.write(cbuf, 3);
      break;
    default:
      ADMUX ^= 1;
      ADCSRA |= B01000000;
      if (chan == 1) {
        cbuf[0] = 0x80 | val[0] >> 3;
        cbuf[1] = (val[0] << 4) & 0x70;
        cbuf[1] |= val[1] >> 6;
        cbuf[2] = val[1] & 0x7F;
        Serial.write(cbuf, 3);
      }
  }
}
  
void loop()
{
  while(Serial.available()) {
    char inChar = (char)Serial.read();
    if (inChar == 'A') {
      channels |= CH1;
    }
    else if (inChar == 'a') {
      channels &= ~CH1;
    }
    else if (inChar == 'B') {
      channels |= CH2;
    }
    else if (inChar == 'b') {
      channels &= ~CH2;
    }
  }
}

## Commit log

2023-10-28 Update lxardoscope_wemos_d1_mini.ino
    fixed calibration
2023-10-29 added schematic
    [wemos_shield.kicad_pcb, wemos_shield.kicad_sch]
2023-10-31 added lxardoscope+ version -8000 samples per second
2023-12-22 Update and rename even_faster.ino to calibration_code.ino
2023-12-23 Update lxardoscope_wemos_d1_mini_vfast.ino
    bitshift changes to equal deviding the adc value by 2 as lxardoscope needs 0-512 whereas the adc spits out 0-1023
